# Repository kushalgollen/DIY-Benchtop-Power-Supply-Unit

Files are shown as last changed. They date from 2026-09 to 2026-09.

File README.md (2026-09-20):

# DIY Benchtop Power Supply

This is a project of designing and assembling a custom laboratory benchtop power supply built inside a repurposed Corsair ATX power supply enclosure. It features an adjustable 0–50V / 5A output stage, auxiliary 5V logic rails, dual 5V USB ports, and an autonomous MOSFET temperature-controlled cooling system.

This is a very fun project in many ways; it felt like an adult version of LEGOs. Side-quest project for my 5DOF robotic arm.

<p align="center">
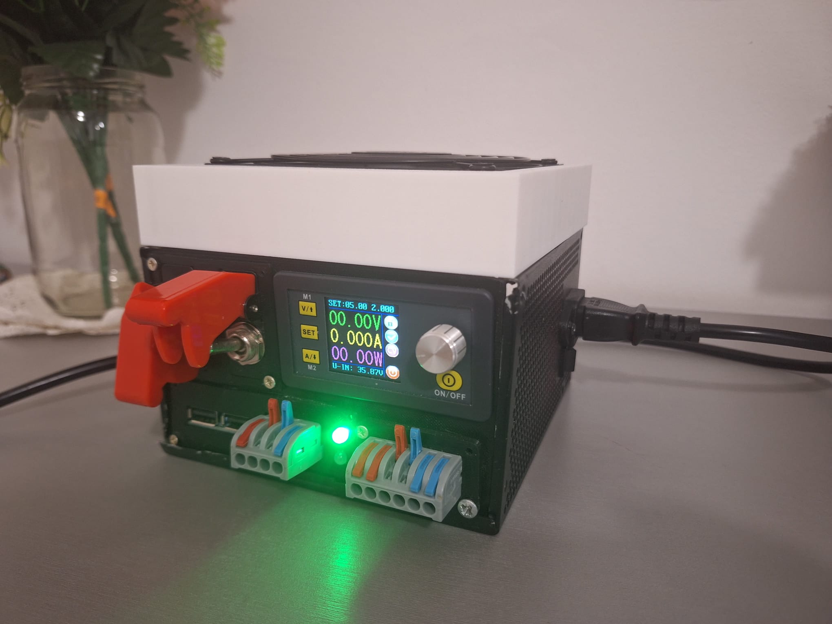
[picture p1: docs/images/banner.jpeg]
  
</p>

---

## Readme Structure

* [What are the necessary components?](#what-are-the-necessary-components)
  * [3D Printed & Mechanical Parts](#3d-printed--mechanical-parts)
  * [Hardware & Tools](#hardware--tools)
  * [Electrical Components](#electrical-components)
* [Connecting All the Components](#connecting-all-the-components)
  * [1. Mains AC Input & Primary Stage](#1-mains-ac-input--primary-stage)
  * [2. Primary Regulated Output (0–50V)](#2-primary-regulated-output-050v)
  * [3. Intermediate 12V Bus](#3-intermediate-12v-bus)
  * [4. Temperature-Controlled Fan Circuit](#4-temperature-controlled-fan-circuit)
  * [5. Fixed 5V Rail & USB Outputs](#5-fixed-5v-rail--usb-outputs)
* [Safety Guidelines](#safety-guidelines)
* [License](#license)

---

## What are the necessary components?

### 3D Printed & Mechanical Parts
* **Enclosure:** Old Corsair ATX power supply case. The original steel chassis provides rigid physical protection, integrated ventilation cutouts, and chassis grounding.
* **Front, Side & Rear Panels:** 3D-printed faceplates (or plywood) designed to mount into the original cable-exit opening of the PSU.
  * *Filament choice:* PETG or ABS/ASA is recommended for heat resistance near internal heatsinks, though PLA works fine if airflow is kept decoupled.
  * *Print settings:* 4 perimeters/walls, 30–40% infill to firmly support tightening binding post nuts.

### Hardware & Tools
* **Soldering Station:** Soldering iron and rosin-core solder wire.
* **Fastening:** Hot glue gun (for wire securing / module standoffs), heat-shrink tubing, and M3 hardware/standoffs.
* **Prototyping:** Perfboard / stripboard for soldering discrete components (fan circuit & 5V regulator).
* **Wiring:** 
  * `14 AWG`: High-current DC path (36V input / 50V output).
  * `20 AWG`: Auxiliary power distribution (12V & 5V rails).
  * `32 AWG`: Low-power signals, LED indicators, and thermistor sense lines.

### Electrical Components

#### Power Modules
* **Primary SMPS:** 180W AC-to-DC step-down power supply board (`100–240V AC` input, `36V 5A DC` output).
* **Main Adjustable DC-DC Module:** Numerical Control Step-Down module (`6–55V` input to `0–50V 5A` output) with digital display and keypad/encoder.
* **Intermediate Step-Down:** LM2596 DC-DC buck converter module (steps down `36V` to `12V`).
* **USB Output Module:** 5V 3A dual USB step-down converter board.
* **Linear Regulator:** LM7805 5V linear voltage regulator in TO-220 package.

#### Cooling & Temperature Control
* **12V Fan:** Stock 12V brushless exhaust fan extracted directly from the Corsair PSU.
* **IRFZ44N N-Channel MOSFET:** Acts as a low-side ground switch for the 12V fan.
* **10k NTC Thermistor:** Attached to the primary SMPS heatsink to monitor operational temperature.
* **10k Variable Resistor:** Trimpot/potentiometer to fine-tune the gate trigger voltage and temperature threshold.

#### Switches, Passives & Connectors
* **Switches:** 
  * `1x` Mains rocker switch (220V AC input).
  * `2x` Dual-position lever toggle switches (one for the 0–50V output rail, one for the 5V rail).
* **Indicators:** 
  * Green LED (indicates active 36V intermediate power).
  * White LED (indicates active 5V output).
* **Capacitors:** `0.33 µF` (input) and `0.1 µF` (output) ceramic/film capacitors for LM7805 stabilization.
* **Terminals:** 4mm banana binding post pairs / DC output jacks.

---

## Connecting All the Components

The system architecture cleanly separates high-voltage input, variable high-power regulation, intermediate power distribution, and thermal management.

<p align="center">
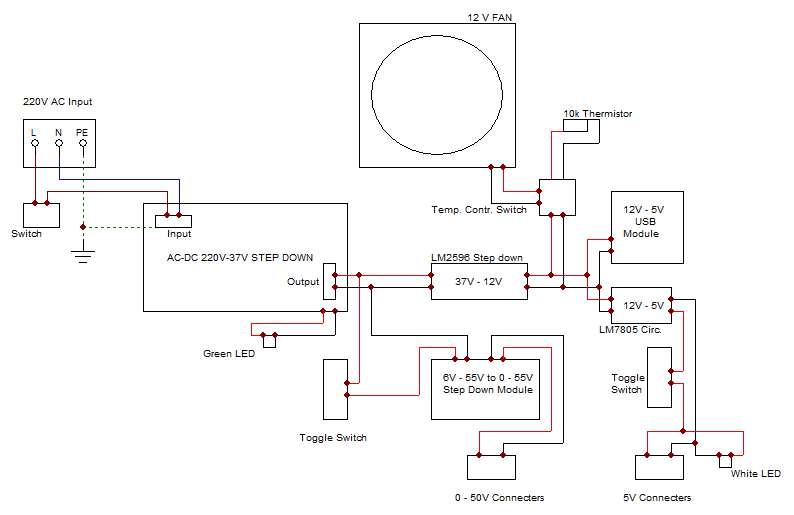
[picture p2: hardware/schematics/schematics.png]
  
</p>

### 1. Mains AC Input & Primary Stage
* The `220V AC` input enters through an IEC socket and passes through an AC-rated toggle/rocker switch on the Line (L) lead.
* **Protective Earth (PE):** Must be bolted directly to the bare metal of the Corsair chassis with a star washer for shock safety.
* The switched AC lines feed into the **180W AC-DC Step-Down** module, producing an isolated `36V DC` rail.
* A **Green LED** is connected across the 36V output (with an appropriate current-limiting resistor) to serve as the master DC power indicator.

### 2. Primary Regulated Output (0–50V)
* The `36V` positive rail runs through the first dual-position toggle switch before reaching the input of the **Numerical Control 0–50V 5A module**.
* This setup allows isolating and setting up your desired output parameters on the screen before physically enabling power to the front **0–50V Banana Terminals**.

### 3. Intermediate 12V Bus
* In parallel with the main output, the `36V` rail feeds the input of an **LM2596 buck converter**.
* Adjust the onboard trimpot of the LM2596 until its output reads exactly `12.0V DC`. This creates the internal auxiliary power bus.

### 4. Temperature-Controlled Fan Circuit: [Circuit Youtube Link](https://youtu.be/iGzHso3EdJY?si=Qx0kQesTtO12RHpX)
* To keep the bench supply dead-silent during light loads, the Corsair 12V fan is not driven continuously.
* The **10k NTC thermistor** and the **10k variable resistor** form a voltage divider biasing the gate pin of the **IRFZ44N MOSFET**:
  * Drain (D) connects to the negative wire of the 12V fan.
  * Source (S) connects to Ground (GND).
  * The positive wire of the 12V fan connects directly to the `+12V` intermediate rail.
* As temperatures inside the chassis rise, thermistor resistance drops, pulling the gate voltage past $V_{GS(th)}$ and kicking on the fan automatically.

### 5. Fixed 5V Rail & USB Outputs
* The `+12V` intermediate bus supplies two independent 5V stages:
  1. **Dual USB Board:** Stepped down directly from 12V to 5V (3A max) for powering microcontrollers or phone charging.
  2. **LM7805 Linear Stage:** Stepped down from 12V with a `0.33 µF` cap across Pin 1 (IN) and GND, and a `0.1 µF` cap across Pin 3 (OUT) and GND to prevent high-frequency oscillations.
* The linear 5V line passes through the second **toggle switch** out to dedicated **5V binding posts**, accompanied by a **White LED** indicating rail activity.

---

## Safety Guidelines

> ⚠️ **DANGER: HIGH VOLTAGE**  
> * Always double-check that the AC power cord is unplugged before touching internal components.
> * Insulate all AC switch and terminals thoroughly with heat-shrink tubing.
> * Ensure the metal enclosure is reliably grounded to the mains Earth wire (PE).

---

## License

Distributed under the [MIT License](LICENSE). Feel free to build, remix, and use it for your laboratory bench!

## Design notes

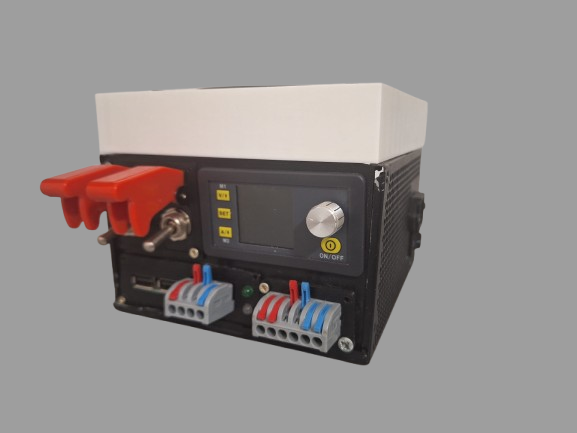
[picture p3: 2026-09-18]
docs/images/image.png

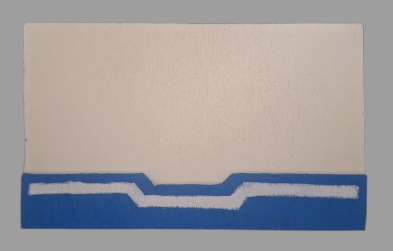
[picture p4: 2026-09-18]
docs/images/back_piece_foto.png

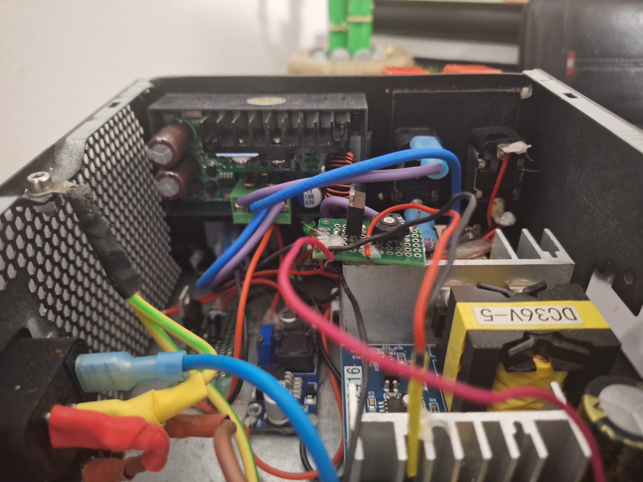
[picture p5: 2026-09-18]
docs/images/internel_1.jpeg

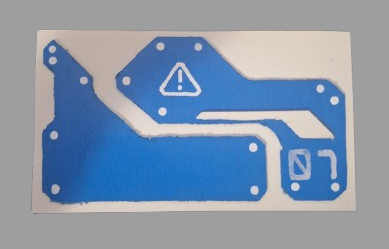
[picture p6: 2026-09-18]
docs/images/side_piece_foto.png

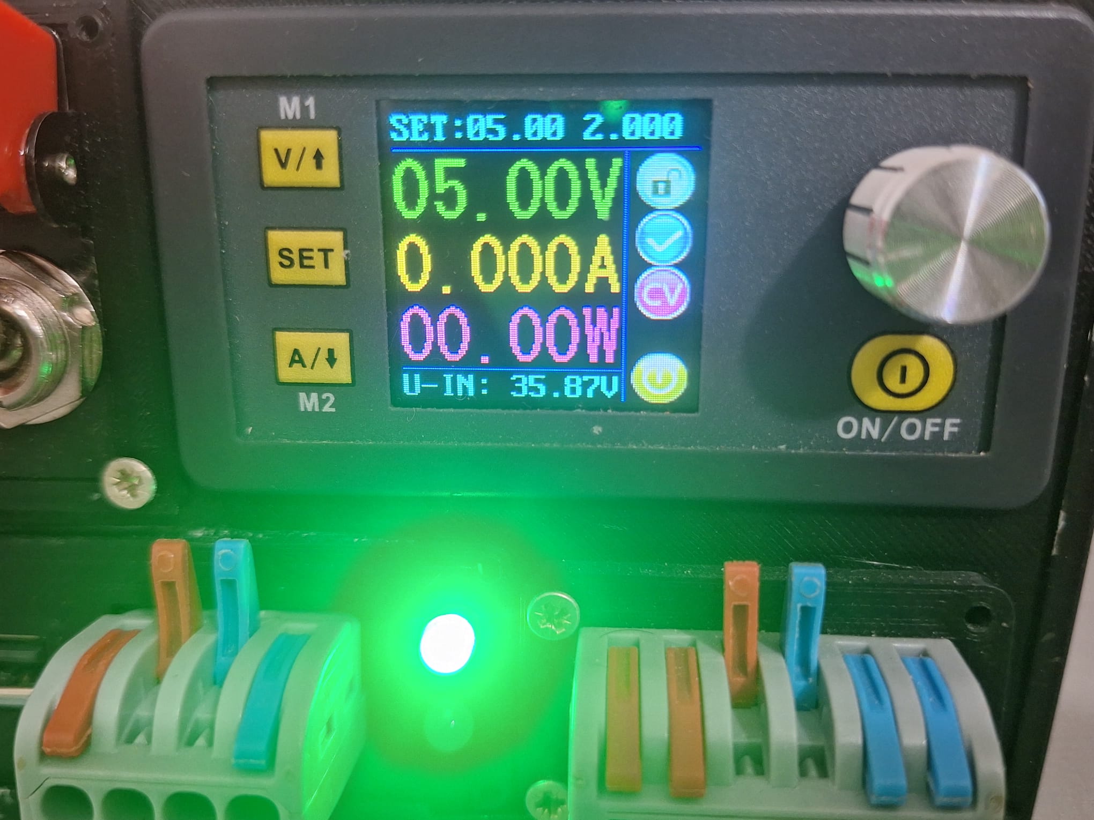
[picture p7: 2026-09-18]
docs/images/func.jpeg

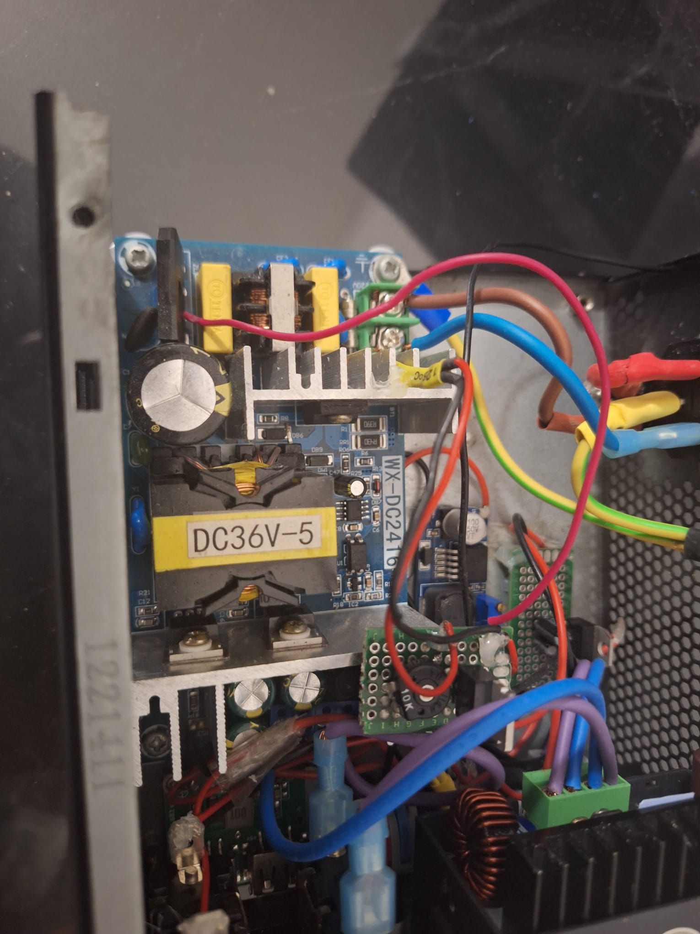
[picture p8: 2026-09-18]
docs/images/internel 2.jpeg

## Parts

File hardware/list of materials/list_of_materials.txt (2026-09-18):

Materials List & required parts:

1. Old Corsair power supply unit: using as case and 12V fan
 
2. Numerical Control DC 6-55V to 0-50V 5A Step Down Power Supply Module

3. 180W AC to DC 100-240V AC to 36V 5A DC Step Down

4. LM2596 Step-Down Buck Converter

5. 5V 3A Dual USB output charging module

6. 5V LM7805 voltage regulator

7. White LED

8. Green LED

9. 0.33 µF Capacitor

10. 0.1 µF Capacitor

11. (x2) Dual position toggle switch with lever

12. Electric connectors/ DC output plugs (as needed)

13. Electrical wires: 14/20/32 AWG

14. Soldering Iron and solder wire

15. Plywood or 3d-printed parts (as needed)

16. Prototyping boards

15. Glue Gun

-- For homemade MOSFET-based temperature controlled switch --

1. 10k Ohm variable resistor 

2. 10k thermistor

3. IRFZ44N N-Chanel Mosfet

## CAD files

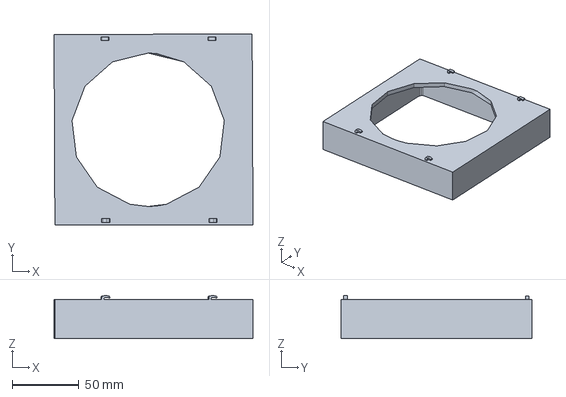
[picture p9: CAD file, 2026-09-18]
mechanical/print_ready/fan_mount.3mf
148.7 x 143.0 x 32.2 mm

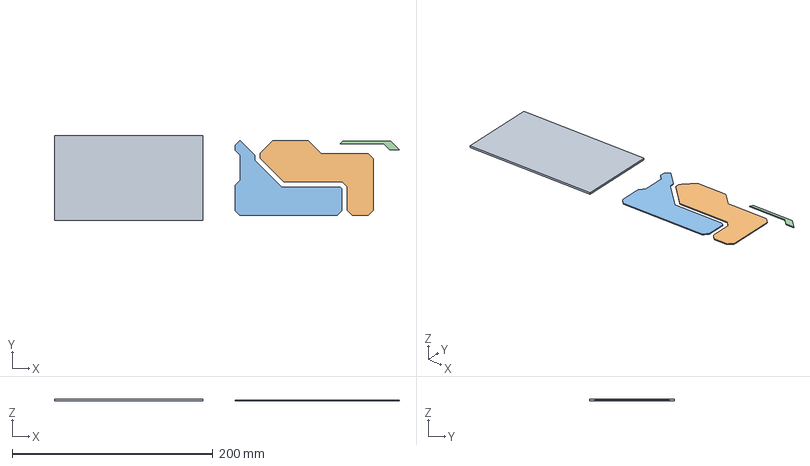
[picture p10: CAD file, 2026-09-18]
mechanical/print_ready/power_supply_side_piece_cyberpunk.3mf
344.1 x 85.0 x 2.00 mm
Corpo1
Corpo2
Corpo3
Corpo4

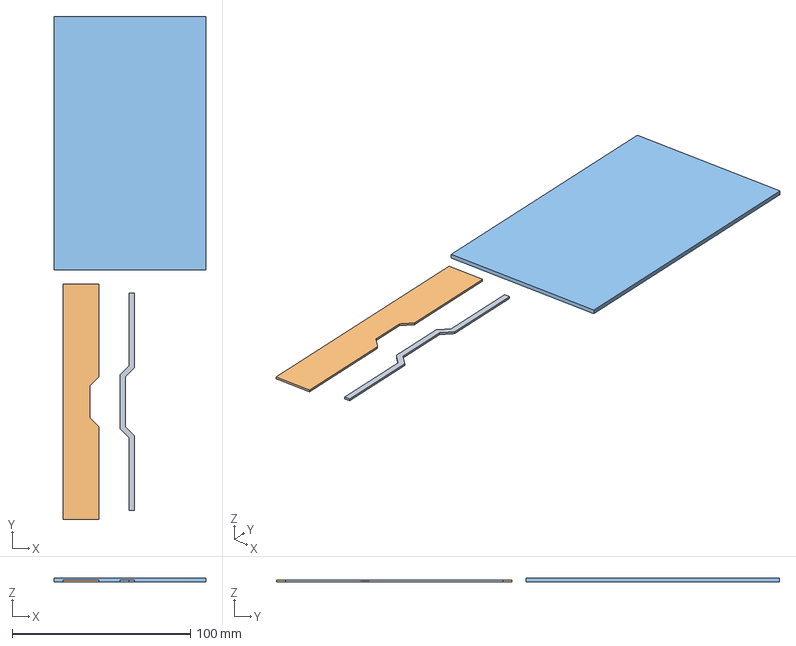
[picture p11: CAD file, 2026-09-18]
mechanical/print_ready/power_supply_back_cayberpunk.3mf
85.0 x 282.0 x 2.00 mm
cyber strand
lower
main

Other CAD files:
mechanical/3d_models/power_supply_back_cayberpunk.f3d
mechanical/3d_models/power_supply_side_piece_cyberpunk.f3d

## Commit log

2026-09-18 Add README for DIY Benchtop Power Supply project
    Added detailed description and features of the DIY Benchtop Power Supply project, including hardware architecture.
2026-09-18 Update safety guidelines for high voltage warnings
2026-09-18 Enhance README with video link and safety guideline updates
    Updated the Temperature-Controlled Fan Circuit section to include a link to the circuit video and modified safety guidelines for clarity.
2026-09-18 Revise panel descriptions in README
    Updated panel descriptions to include side panels and simplified material options.
2026-09-18 Update schematic image path in README.md
